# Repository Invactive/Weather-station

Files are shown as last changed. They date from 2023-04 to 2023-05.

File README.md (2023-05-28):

# Weather-station
The PCB project of an external, autonomous weather station including a battery-powered system for monitoring atmospheric conditions using 5 weather sensors. 
The STM32 microcontroller was used to operate the sensors, while a LoRaWAN radio communication module was utilized for long-range, wireless data transmission.

## General information:

The PCB project was implemented on a FR-4 laminate with a thickness of 1.5mm and dimensions of 90x32mm, consisting of two signal layers. 

The copper tracks have a thickness of 35μm. 

The board includes a 2-pin JST-XH power connector, a programmer/debugger 8-pin connector for the microcontroller, and an SMA antenna connector. 

To obtain +5V and +3.3V voltages, two voltage converters were used (with a maximum supply voltage of +5.5V). 

The maximum current consumption calculated for the entire circuit is approximately 500mA. 

The device can be battery powered (max. input voltage 5.5V).

Data from the sensors are transmitted via I2C, SPI and Analog.

Project includes: schematics, PCB, BOM, datasheets, 3D view, Gerber and drill files.

## Modules:
- STM32 MCU
- 5 weather conditions sensors
- LoRaWAN module for wireless communication
- Battery voltage measurement unit 
- Power supply unit (includes boost converters TPS61023DRLR)

## Main Components:
- MCU - STM32F301C8T6TR
- LoraWAN - RFM95W-868S2R
- Metal Oxide Gas Sensor - MICS-6814
- Air Pressure Sensor - KP254
- Humidity Sensor - HIH6020-021-001
- Temperature Sensor - TMP36GT9Z
- Ambient Light Sensor - BH1750FVI-TR
- Boost Converter - TPS61023DRLR

## Schematics:
[](Electrical_Schematics/weather_station_schematics.pdf)

## PCB:
[](src/PCB.pdf)
[](src/PCB_front.pdf)
[](src/PCB_back.pdf)

## 3D Views:
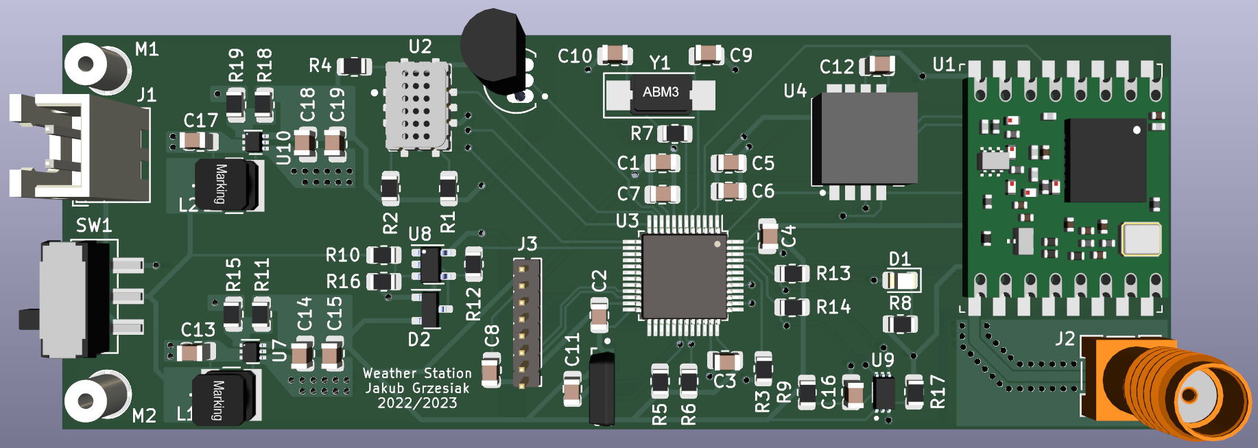
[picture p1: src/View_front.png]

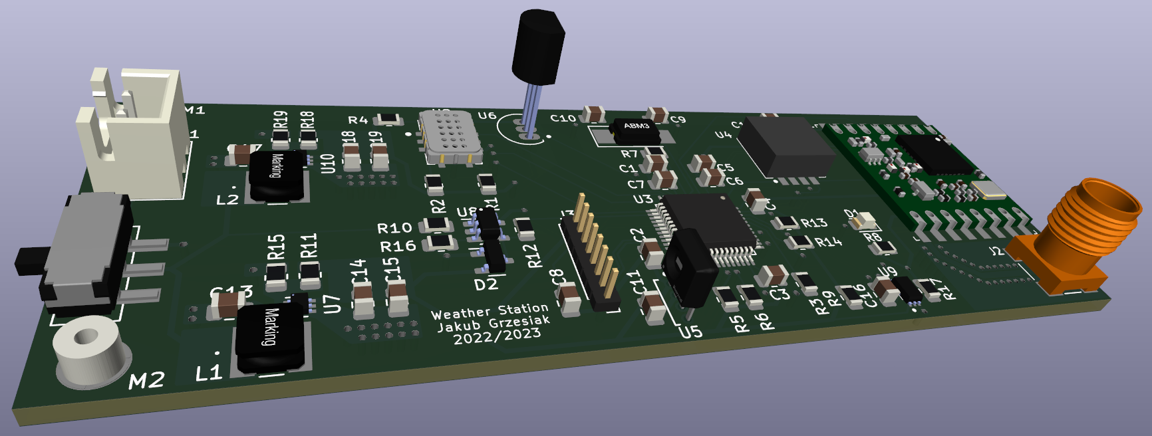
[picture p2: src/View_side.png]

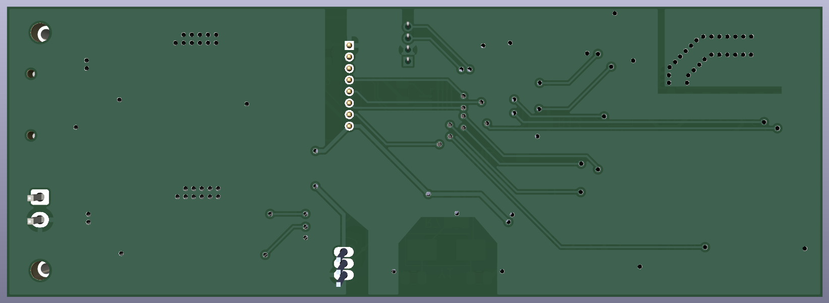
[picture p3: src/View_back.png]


---
Project designed in KiCAD 6.0.

Author: Jakub Grzesiak

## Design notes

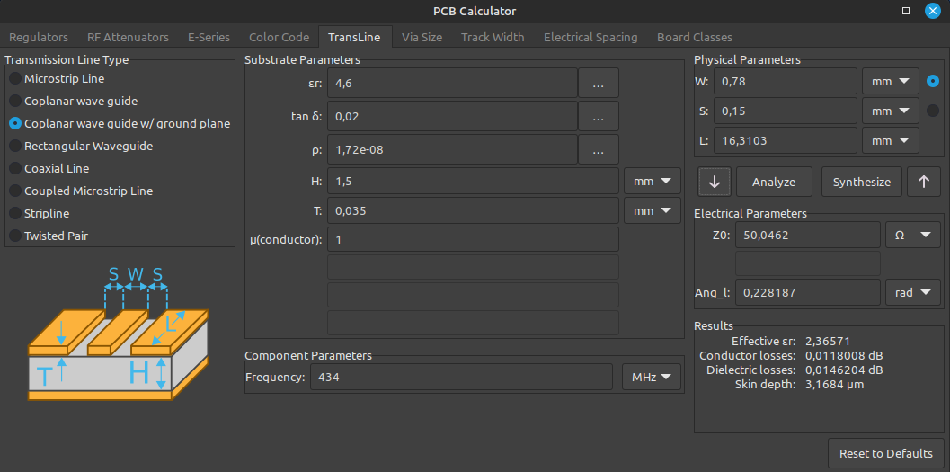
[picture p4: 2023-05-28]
src/imp_calc.png

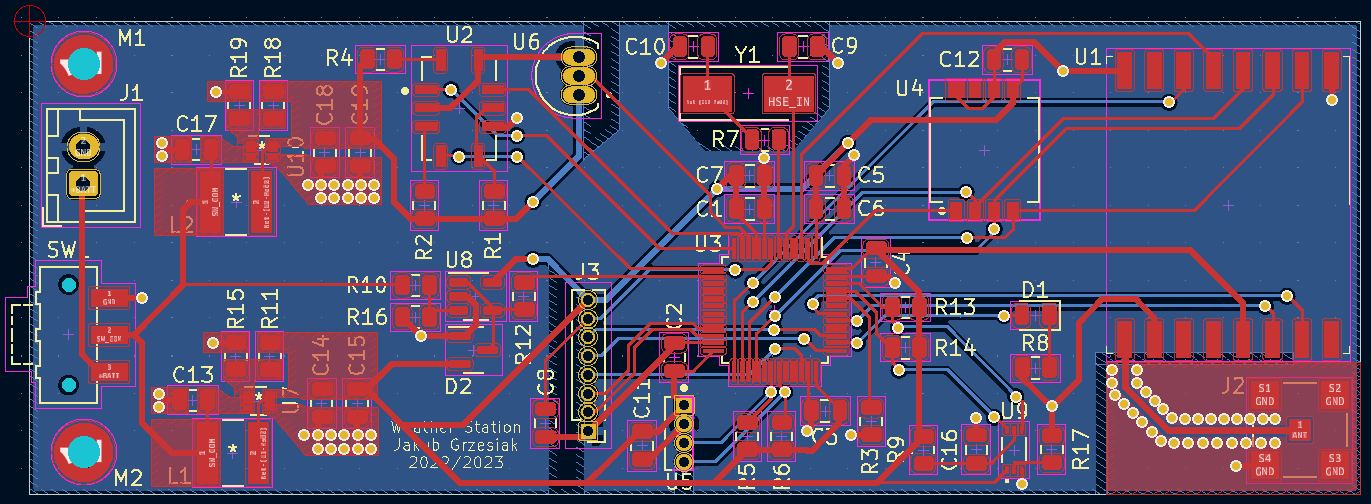
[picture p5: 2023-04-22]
src/PCB.png

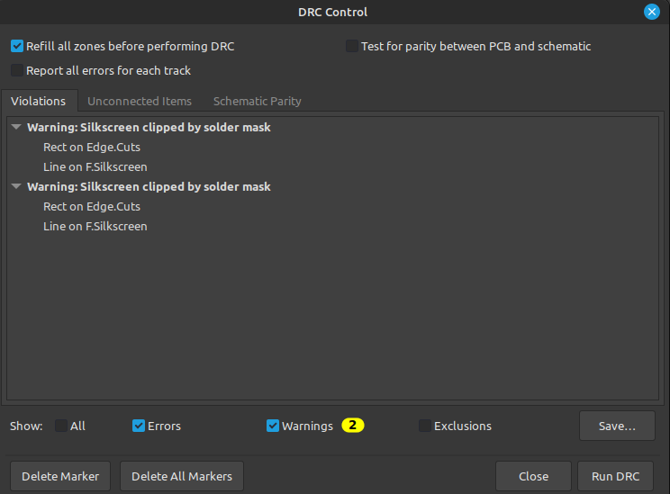
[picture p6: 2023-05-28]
src/DRC.png

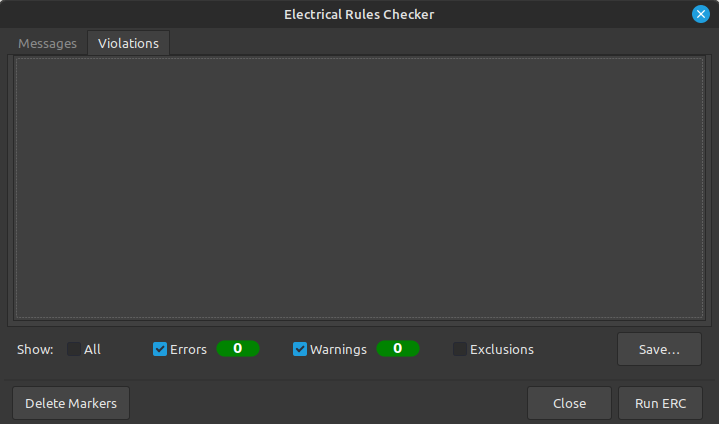
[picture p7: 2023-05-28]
src/ERC.png

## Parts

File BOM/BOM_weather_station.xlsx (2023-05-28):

Project: | Weather Station
Author: | Jakub Grzesiak
Source: | /home/jakub/Weather station/KiCAD_Project_Files/weather_station.kicad_sch
Date: | 2023-01-02 00:04
Tool: | Eeschema (6.0.7)
Generator: | /usr/share/kicad/plugins/bom_csv_grouped_by_value_with_fp.py
Number of components per 1 PCB: | 58
No. | Ref | Quantity | Value | Name | Footprint | Description | Vendor | Unit cost (1 item) | Price (1 PCB) | Unit cost (10 items) | Price (10 PCB) | Unit cost (100 items) | Price (100 PCB) | Link
1 | C1, C2, C3, C4, C8, C12 | 6 | 100nF | C | Capacitor_SMD:C_0805_2012Metric | Unpolarized capacitor | Mouser.pl | 0.48 zł | 2.89 zł | 0.11 zł | 6.66 zł | 0.05 zł | 31.80 zł | https://www.mouser.pl/ProductDetail/Samsung-Electro-Mechanics/CL21B104KACNFNC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
2 | C5 | 1 | 4.7uF | C | Capacitor_SMD:C_0805_2012Metric | Unpolarized capacitor | Mouser.pl | 0.48 zł | 0.48 zł | 0.18 zł | 1.83 zł | 0.15 zł | 14.90 zł | https://www.mouser.pl/ProductDetail/Samsung-Electro-Mechanics/CL21A475KPFNNNG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
3 | C6 | 1 | 1uF | C | Capacitor_SMD:C_0805_2012Metric | Unpolarized capacitor | Mouser.pl | 0.48 zł | 0.48 zł | 0.18 zł | 1.83 zł | 0.15 zł | 14.90 zł | https://www.mouser.pl/ProductDetail/Samsung-Electro-Mechanics/CL21B105KOFNNWE?qs=yOVawPpwOwmk953lizFBNA%3D%3D
4 | C7 | 1 | 10nF | C | Capacitor_SMD:C_0805_2012Metric | Unpolarized capacitor | Mouser.pl | 0.48 zł | 0.48 zł | 0.12 zł | 1.15 zł | 0.10 zł | 9.60 zł | https://www.mouser.pl/ProductDetail/Samsung-Electro-Mechanics/CL21B103KAANNNC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
5 | C9, C10 | 2 | 20pF | C | Capacitor_SMD:C_0805_2012Metric | Unpolarized capacitor | Mouser.pl | 0.56 zł | 1.11 zł | 0.26 zł | 5.20 zł | 0.20 zł | 40.40 zł | https://www.mouser.pl/ProductDetail/YAGEO/CC0805JRNPO9BN200
6 | C11 | 1 | 0.22uF | C | Capacitor_SMD:C_0805_2012Metric | Unpolarized capacitor | Mouser.pl | 0.72 zł | 0.72 zł | 0.34 zł | 3.37 zł | 0.25 zł | 24.50 zł | https://www.mouser.pl/ProductDetail/KYOCERA-AVX/08053C224K4T2A
7 | C13 | 1 | 2.2uF 4.06mR | C | Capacitor_SMD:C_0805_2012Metric | Unpolarized capacitor | Mouser.pl | 0.91 zł | 0.91 zł | 0.39 zł | 3.90 zł | 0.31 zł | 30.80 zł | https://www.mouser.pl/ProductDetail/TDK/C2012X5R1A225K085AA?qs=iuKcRwBk4Q80WRz1xS%2FJlw%3D%3D
8 | C14, C15, C18, C19 | 4 | 2.2uF 7.77mR | C | Capacitor_SMD:C_0805_2012Metric | Unpolarized capacitor | TME.eu | 1.18 zł | 4.72 zł | 1.18 zł | 47.16 zł | 0.78 zł | 310.00 zł | https://www.tme.eu/pl/en/details/grm21br71e225ka73l/mlcc-smd-capacitors/murata/
9 | C16 | 1 | 0.1uF | C | Capacitor_SMD:C_0805_2012Metric | Unpolarized capacitor | Digikey.pl | 0.45 zł | 0.45 zł | 0.20 zł | 1.99 zł | 0.11 zł | 10.90 zł | https://www.digikey.pl/en/products/detail/CL21B104KBCNNNC/1276-1003-1-ND/3889089?curr=pln
10 | C17 | 1 | 10uF 3mR | C | Capacitor_SMD:C_0805_2012Metric | Unpolarized capacitor | Digikey.pl | 0.63 zł | 0.63 zł | 0.47 zł | 4.67 zł | 0.22 zł | 21.90 zł | https://www.digikey.pl/en/products/detail/C0805C106K8PAC7800/399-C0805C106K8PAC7800CT-ND/1090920?curr=pln
11 | D1 | 1 | LED | LED | LED_SMD:LED_0805_2012Metric | Light emitting diode | Digikey.pl | 0.86 zł | 0.86 zł | 0.86 zł | 8.60 zł | 0.68 zł | 68.40 zł | https://www.digikey.pl/en/products/detail/150080GS75000/732-4983-1-ND/4489913?curr=pln
12 | D2 | 1 | BAT54S | BAT54S | Package_TO_SOT_SMD:SOT-23 | Schottky barrier diode | Mouser.pl | 0.87 zł | 0.87 zł | 0.82 zł | 8.23 zł | 0.45 zł | 45.20 zł | https://www.mouser.pl/ProductDetail/onsemi/BAT54SLT1G?qs=vLkC5FC1VN9oCh8qaBIZiQ%3D%3D
13 | J1 | 1 | JST-XH | B2B-XH-A(LF)(SN) | Connector_JST:JST_XH_B2B-XH-A_1x02_P2.50mm_Vertical | JST-XH header connector 2-pin | Farnell.com | 0.42 zł | 0.42 zł | 0.42 zł | 4.20 zł | 0.42 zł | 42.00 zł | https://pl.farnell.com/jst-japan-solderless-terminals/b2b-xh-a-lf-sn/header-vertical-2way/dp/1516276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
14 | J2 | 1 | SMA Antenna Connector | 73251-1350 | MOLEX_SMA_73251-1350:MOLEX_73251-1350 | SMA header antenna connector | Digikey.pl | 19.12 zł | 19.12 zł | 16.82 zł | 168.20 zł | 13.38 zł | 1338.00 zł | https://www.digikey.pl/en/products/detail/0732511350/WM9357-ND/3468834?curr=pln
15 | J3 | 1 | Debug Connector | Conn_01x08_Male | Connector_PinHeader_1.27mm:PinHeader_1x08_P1.27mm_Vertical | Generic connector, single row, 01x08, script generated (kicad-library-utils/schlib/autogen/connector/) | TME.eu | 0.93 zł | 0.93 zł | 0.93 zł | 9.26 zł | 0.58 zł | 58.10 zł | https://www.tme.eu/en/details/zl319-8p/pin-headers/connfly/ds1031-01-1-8p8bv3-1/
16 | L1, L2 | 2 | 1uH 17mR | L | 74404043010A:74404043010A | Inductor 74404043010A | Mouser.pl | 3.03 zł | 6.06 zł | 3.03 zł | 60.60 zł | 1.93 zł | 386.00 zł | https://www.mouser.pl/ProductDetail/Wurth-Elektronik/74404043010A?qs=h3%2Fj8evtlm0a71lUla1Ygg%3D%3D
17 | R1 | 1 | 820R | R | Resistor_SMD:R_0805_2012Metric | Resistor | Digikey.pl | 0.45 zł | 0.45 zł | 0.21 zł | 2.08 zł | 0.09 zł | 8.50 zł | https://www.digikey.pl/en/products/detail/CRGCQ0805F820R/A129748CT-ND/8577580?curr=pln
18 | R2 | 1 | 27R | R | Resistor_SMD:R_0805_2012Metric | Resistor | Digikey.pl | 0.45 zł | 0.45 zł | 0.21 zł | 2.08 zł | 0.09 zł | 8.50 zł | https://www.digikey.pl/en/products/detail/CRG0805F27R/A126357CT-ND/7603412?curr=pln
19 | R3, R17 | 2 | 10k | R | Resistor_SMD:R_0805_2012Metric | Resistor | Digikey.pl | 0.45 zł | 0.90 zł | 0.16 zł | 3.18 zł | 0.07 zł | 13.00 zł | https://www.digikey.pl/en/products/detail/CRGCQ0805J10K/A130140CT-ND/8577972?curr=pln
20 | R4 | 1 | 130R | R | Resistor_SMD:R_0805_2012Metric | Resistor | Digikey.pl | 0.45 zł | 0.45 zł | 0.30 zł | 3.04 zł | 0.12 zł | 12.30 zł | https://www.digikey.pl/en/products/detail/CRCW0805130RFKEA/541-130CCT-ND/1180681?curr=pln
21 | R5, R6 | 2 | 2k2 | R | Resistor_SMD:R_0805_2012Metric | Resistor | Digikey.pl | 0.45 zł | 0.90 zł | 0.17 zł | 3.36 zł | 0.07 zł | 13.60 zł | https://www.digikey.pl/en/products/detail/CRGCQ0805J2K2/A130136CT-ND/8577968?curr=pln
22 | R7 | 1 | 390R | R | Resistor_SMD:R_0805_2012Metric | Resistor | Digikey.pl | 0.45 zł | 0.45 zł | 0.40 zł | 3.99 zł | 0.15 zł | 15.40 zł | https://www.digikey.pl/en/products/detail/ERJ-6ENF3900V/P390CCT-ND/1746861?curr=pln
23 | R8 | 1 | 100R | R | Resistor_SMD:R_0805_2012Metric | Resistor | Digikey.pl | 0.50 zł | 0.50 zł | 0.44 zł | 4.39 zł | 0.17 zł | 16.90 zł | https://www.digikey.pl/en/products/detail/CRGH0805F100R/A126416CT-ND/7603471?curr=pln
24 | R9 | 1 | 1k | R | Resistor_SMD:R_0805_2012Metric | Resistor | Digikey.pl | 0.45 zł | 0.45 zł | 0.16 zł | 1.63 zł | 0.07 zł | 6.70 zł | https://www.digikey.pl/en/products/detail/RC0805FR-101KL/13-RC0805FR-101KLCT-ND/13694478?curr=pln
25 | R10, R15, R16, R19 | 4 | 100k | R | Resistor_SMD:R_0805_2012Metric | Resistor | Mouser.pl | 0.48 zł | 1.92 zł | 0.25 zł | 10.00 zł | 0.11 zł | 44.40 zł | https://www.mouser.pl/ProductDetail/Bourns/CR0805AFX-1003ELF
26 | R11 | 1 | 453k | R | Resistor_SMD:R_0805_2012Metric | Resistor | Mouser.pl | 0.53 zł | 0.53 zł | 0.40 zł | 4.04 zł | 0.16 zł | 15.90 zł | https://www.mouser.pl/ProductDetail/Panasonic/ERJ-6ENF4533V?qs=sGAEpiMZZMtlubZbdhIBINbsJb0hdM3zu28clQM34zY%3D
27 | R12 | 1 | 200R | R | Resistor_SMD:R_0805_2012Metric | Resistor | Digikey.pl | 0.45 zł | 0.45 zł | 0.11 zł | 1.13 zł | 0.05 zł | 4.70 zł | https://www.digikey.pl/en/products/detail/CR0805-FX-2000ELF/118-CR0805-FX-2000ELFCT-ND/3925388?curr=pln
28 | R13, R14 | 2 | 4k7 | R | Resistor_SMD:R_0805_2012Metric | Resistor | Digikey.pl | 0.45 zł | 0.90 zł | 0.21 zł | 4.16 zł | 0.09 zł | 17.00 zł | https://www.digikey.pl/en/products/detail/CRGCQ0805F4K7/A129757CT-ND/8577589?curr=pln
29 | R18 | 1 | 732k | R | Resistor_SMD:R_0805_2012Metric | Resistor | Mouser.pl | 0.48 zł | 0.48 zł | 0.40 zł | 4.04 zł | 0.16 zł | 15.90 zł | https://www.mouser.pl/ProductDetail/Panasonic/ERJ-6ENF7323V
30 | SW1 | 1 | SW_MAIN_PWR | SW_SPDT | Button_Switch_SMD:SW_SPDT_CK-JS102011SAQN | Switch, single pole double throw | Digikey.pl | 2.99 zł | 2.99 zł | 2.90 zł | 29.04 zł | 2.79 zł | 279.40 zł | https://www.digikey.pl/en/products/detail/c-k/JS102011SAQN/1640095
31 | U1 | 1 | RFM95W-868S2 | RFM95W-868S2 | RF_Module:HOPERF_RFM69HW | LoraWAN module | TME.eu | 36.36 zł | 36.36 zł | 30.71 zł | 397.10 zł | 25.11 zł | 2511.00 zł | https://www.tme.eu/pl/en/details/rfm95w-868s2/rf-modules/hope-microelectronics/rfm95w-868s2r/
32 | U2 | 1 | MICS-6814 | MICS-6814 | MICS-6814:SENSOR_MICS-6814 | Air Quality Sensors MOS Triple Sensor | Mouser.pl | 58.49 zł | 58.49 zł | 53.73 zł | 573.30 zł | 53.20 zł | 5320.00 zł | https://www.mouser.pl/ProductDetail/Amphenol-SGX-Sensortech/MICS-6814?qs=YCa%2FAAYMW01pNK%252BnW3Jo7g%3D%3D
33 | U3 | 1 | STM32F301C8T6TR | STM32F301C8Tx | Package_QFP:LQFP-48_7x7mm_P0.5mm | ARM Cortex-M4 MCU, 64KB flash, 16KB RAM, 72MHz, 2-3.6V, 37 GPIO, LQFP-48 | Farnell.com | 18.83 zł | 18.83 zł | 16.92 zł | 169.20 zł | 13.84 zł | 1384.00 zł | https://pl.farnell.com/stmicroelectronics/stm32f301c8t6tr/mcu-32bit-cortex-m4-72mhz-lqfp/dp/2503249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
34 | U4 | 1 | KP254 | KP254 | KP254:Infineon-KP254-Manufacturer_Recommended | KP254 | Farnell.com | 39.61 zł | 39.61 zł | 31.55 zł | 315.50 zł | 25.16 zł | 2516.00 zł | https://pl.farnell.com/infineon/kp254xtma2/pressure-sensor-absolute-40kpa/dp/3816971?CMP=GRHB-OCTOPART
35 | U5 | 1 | HIH6020-021-001 | HIH6020-021-001 | HIH7120-021-001:Honeywell-HIH7120-021-001-Recommended_Land_Pattern_ | HIH7120-021-001 | Mouser.pl | 63.35 zł | 63.35 zł | 57.62 zł | 576.20 zł | 48.97 zł | 4897.00 zł | https://www.mouser.pl/ProductDetail/Honeywell/HIH6020-021-001?qs=jvB%252BdWhGd43%2FZG9ey9bbTQ%3D%3D
36 | U6 | 1 | TMP36GT9Z | TMP36GT9Z | TMP36GT9Z:TO92127P521H733-3 | Board Mount Temperature Sensor | Mouser.pl | 9.76 zł | 9.76 zł | 8.75 zł | 87.50 zł | 7.02 zł | 702.00 zł | https://www.mouser.pl/ProductDetail/Analog-Devices/TMP36GT9Z?qs=WIvQP4zGanhT97N47MSoHw%3D%3D
37 | U7, U10 | 2 | TPS61023DRLR | TPS61023DRLR | TPS61023DRLR:TPS61023DRLR | Boost converter | Mouser.pl | 5.92 zł | 11.84 zł | 5.34 zł | 106.80 zł | 4.14 zł | 828.00 zł | https://www.mouser.pl/ProductDetail/Texas-Instruments/TPS61023DRLT?qs=BJlw7L4Cy78Zr3IJIU3gNw%3D%3D&vip=1
38 | U8 | 1 | INA180A1 | INA180A1 | Package_TO_SOT_SMD:SOT-23-5 | Current Sense Amplifier, 1 Circuit, Rail-to-Rail, 26V, Gain 20 V/V, SOT-23-5 | Mouser.pl | 2.45 zł | 2.45 zł | 2.09 zł | 20.90 zł | 1.56 zł | 156.00 zł | https://www.mouser.pl/ProductDetail/Texas-Instruments/INA180A1IDBVR?qs=5aG0NVq1C4wnkaOukGk95A%3D%3D
39 | U9 | 1 | BH1750FVI-TR | BH1750FVI-TR | BH1750FVI-TR:XDCR_BH1750FVI-TR | Ambient light sensor | Farnell.com | 21.06 zł | 21.06 zł | 13.89 zł | 138.90 zł | 13.33 zł | 1333.00 zł | https://pl.farnell.com/rohm/bh1750fvi-tr/ambient-light-sensor-i2c-wsof/dp/2421284?CMP=GRHB-OCTOPART
40 | Y1 | 1 | ABM3-8.000MHZ-D2Y | ABM3-8.000MHZ-D2Y | Crystal:Crystal_SMD_Abracon_ABM3-2Pin_5.0x3.2mm_HandSoldering | Miniature ceramic SMD crystal | Farnell.com | 2.22 zł | 2.22 zł | 2.22 zł | 22.20 zł | 2.13 zł | 213.00 zł | https://pl.farnell.com/abracon/abm3-8-000mhz-d2y-t/crystal-8mhz-18pf-smd/dp/2101329?CMP=GRHB-OCTOPART
41 |  | 1 | TI.85.2113 | TI.85.2113 |  | External antenna 868MHZ TERMINAL DIPOLE ANTENNA | Mouser.pl | 40.93 zł | 40.93 zł | 40.93 zł | 409.30 zł | 32.71 zł | 3271.00 zł | https://www.mouser.pl/ProductDetail/Taoglas/TI.85.2113?qs=P1JMDcb91o7IOmGnFabR3w%3D%3D
 |  |  |  |  |  |  | Cost Summary | 1 PCB |  | 10 PCB |  | 100 PCB
 |  |  |  |  |  |  |  | Total | Per 1 PCB | Total | Per 1 PCB | Total | Per 1 PCB
 |  |  |  |  |  |  | Total cost of components: | 357.85 zł | 357.85 zł | 3229.91 zł | 296.38 zł | 26050.60 zł | 251.12 zł
 |  |  |  |  |  |  | PCB manufacturing cost: | 8.74 zł | 8.74 zł | 21.86 zł | 2.19 zł | 94.42 zł | 0.94 zł
 |  |  |  |  |  |  | Total: | 366.59 zł | 366.59 zł | 3251.77 zł | 298.57 zł | 26145.02 zł | 252.06 zł

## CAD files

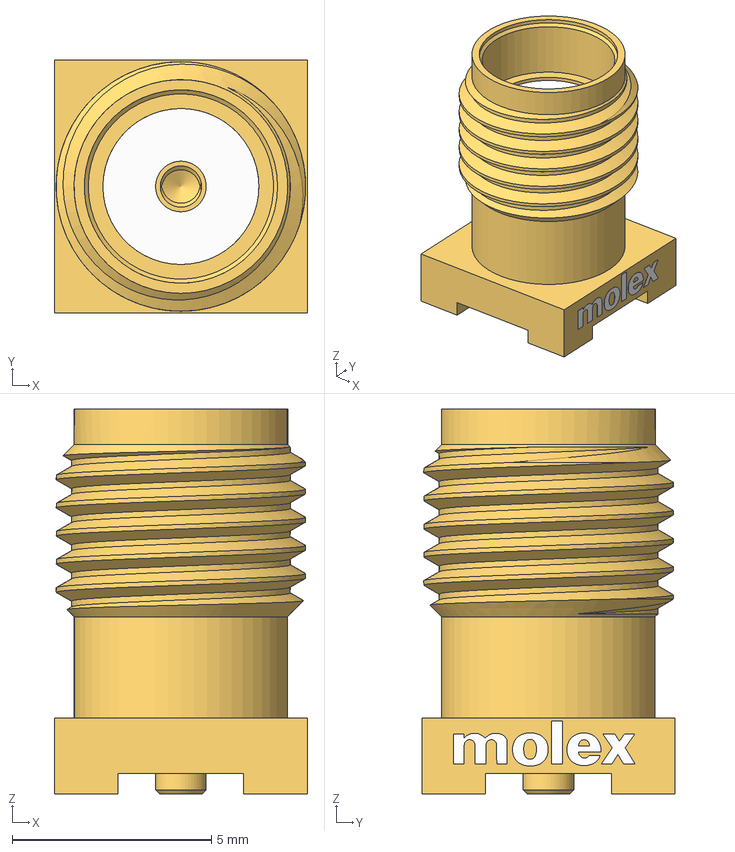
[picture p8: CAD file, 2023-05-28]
3D_Models/Molex_-_73251-1350.step
6.35 x 6.35 x 9.66 mm
isolator
Molex

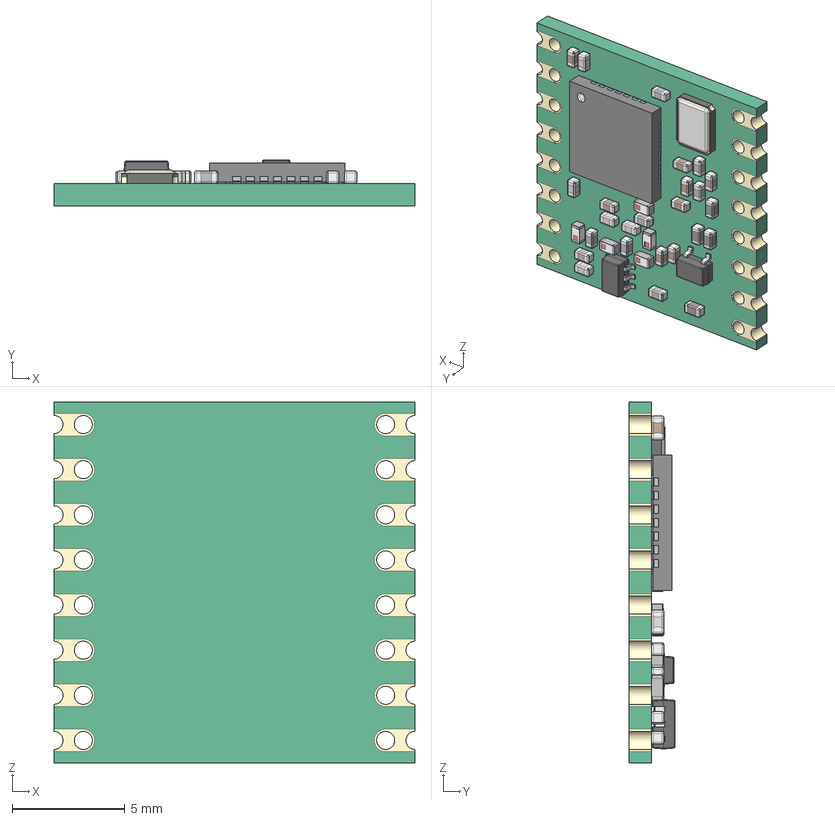
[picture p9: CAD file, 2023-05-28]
3D_Models/RFM95 LoRa v15.step
16.0 x 2.04 x 16.0 mm
QFN 28
SMD Crystal
CAP 0403 x 8
CAP Ceramic 0403 x 8
Res 0403 x 4
CAP ML 0403 x 5
SOT-323
Inductor SMD 0403 x 5
SOT-363

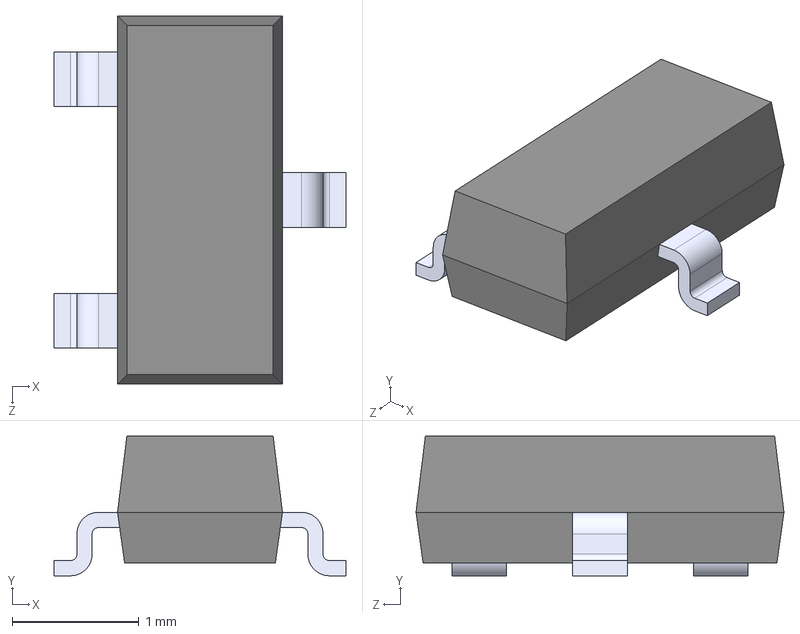
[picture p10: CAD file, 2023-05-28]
3D_Models/BAT54S,215.STEP
2.30 x 1.10 x 2.90 mm

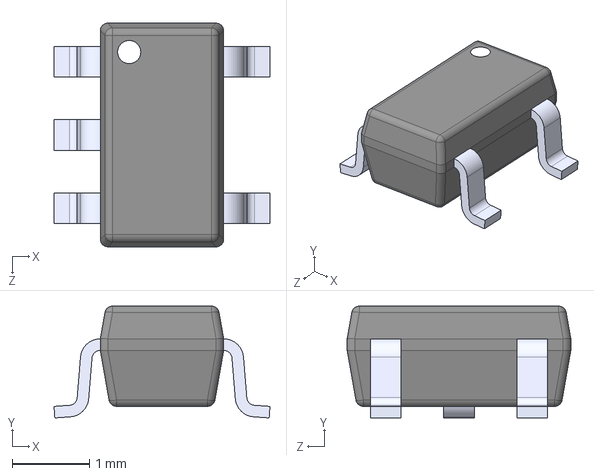
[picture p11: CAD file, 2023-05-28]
3D_Models/INA180B3IDBVR.STEP
2.80 x 1.45 x 2.90 mm

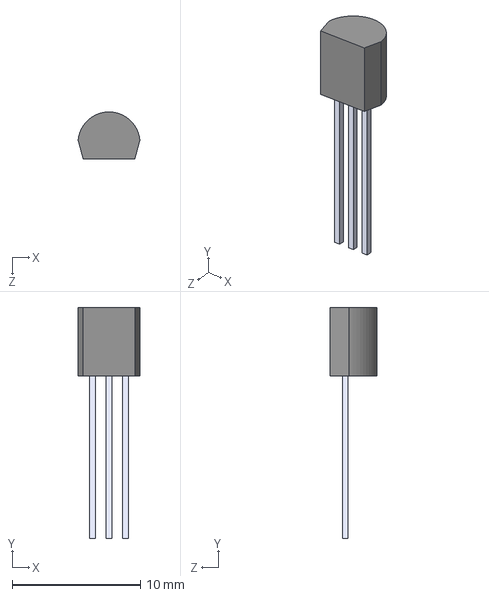
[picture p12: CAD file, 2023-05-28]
3D_Models/TMP36GT9Z--3DModel-STEP-269445.STEP
4.83 x 18.0 x 3.68 mm

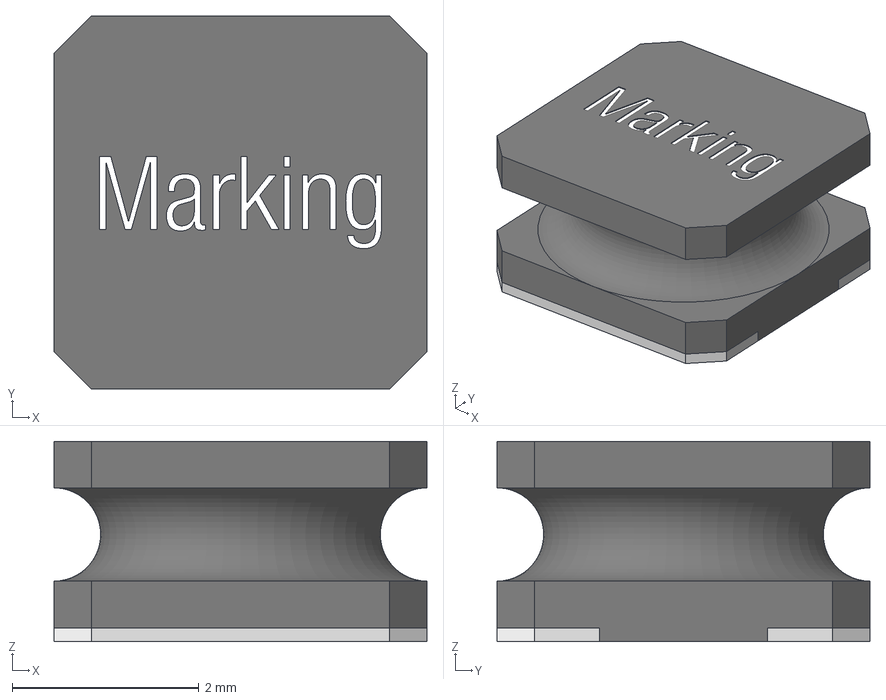
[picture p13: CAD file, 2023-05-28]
3D_Models/Download_STP_WE-LQS-4025 (rev1).stp
4.00 x 4.00 x 2.15 mm
Core
Contact x 2
Glue

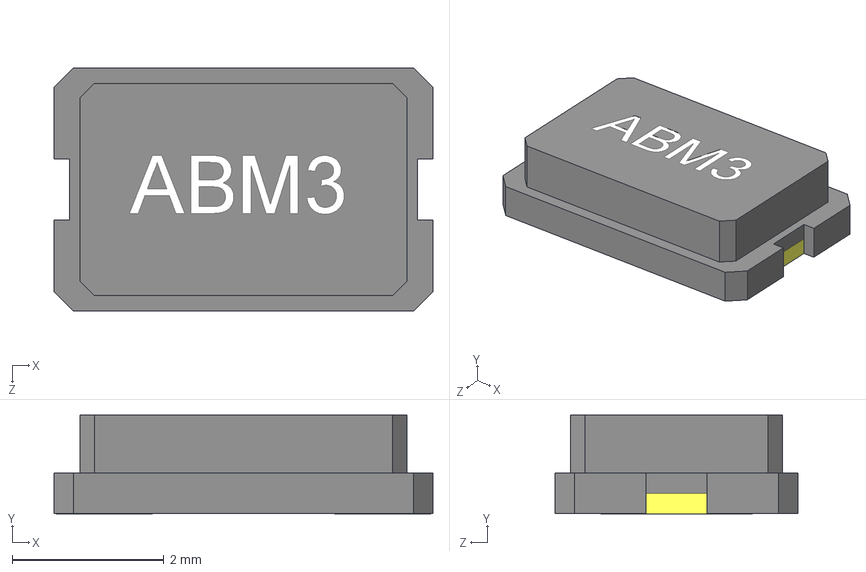
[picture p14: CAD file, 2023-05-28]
3D_Models/ABM3-8.000MHZ-D2Y-T--3DModel-STEP-400430.STEP
5.00 x 1.30 x 3.20 mm

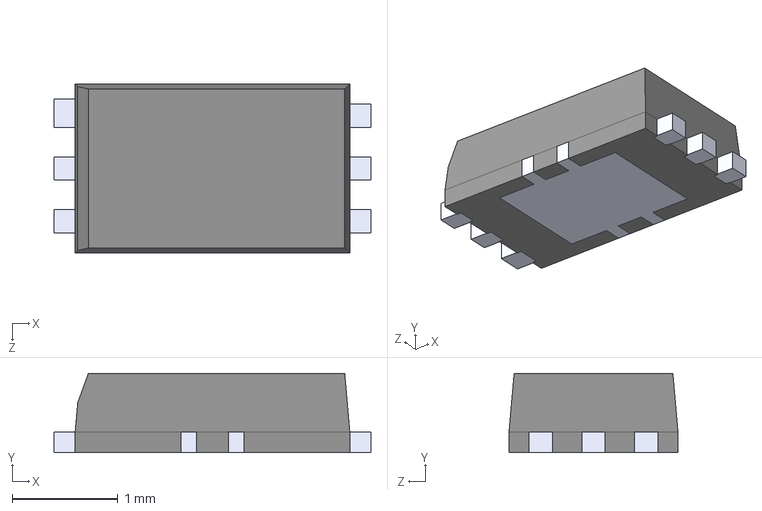
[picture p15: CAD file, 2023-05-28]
3D_Models/BH1750FVI-TR--3DModel-STEP-56544.STEP
3.00 x 0.75 x 1.60 mm

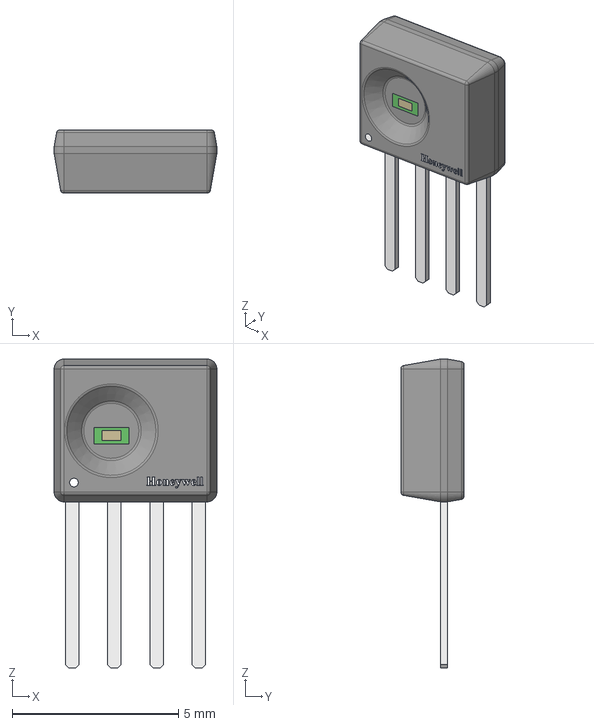
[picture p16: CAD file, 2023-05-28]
3D_Models/Honeywell_-_HIH7120-021-001.step
4.90 x 1.91 x 9.30 mm

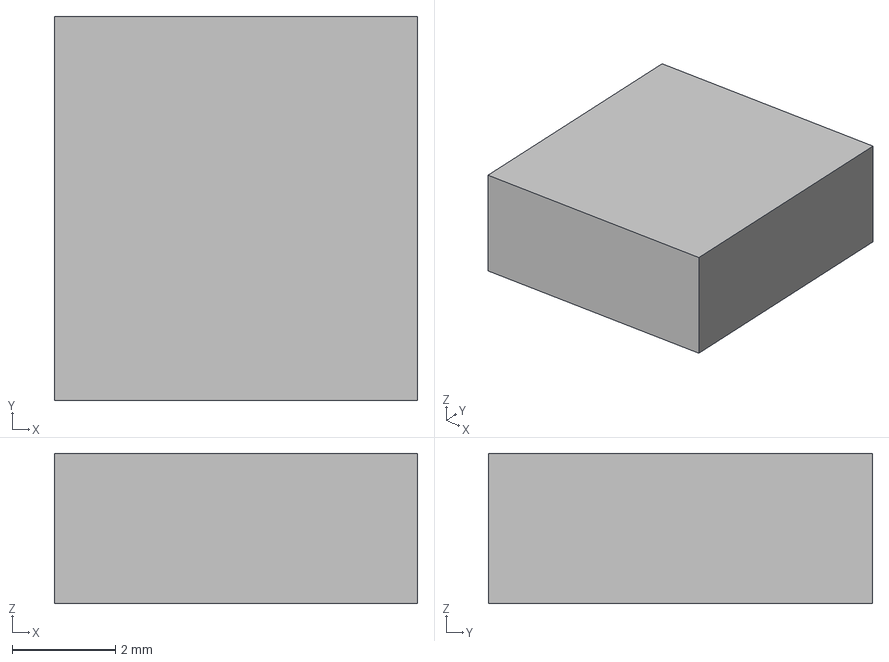
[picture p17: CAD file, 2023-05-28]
3D_Models/Infineon_-_KP254.step
7.02 x 7.42 x 2.90 mm

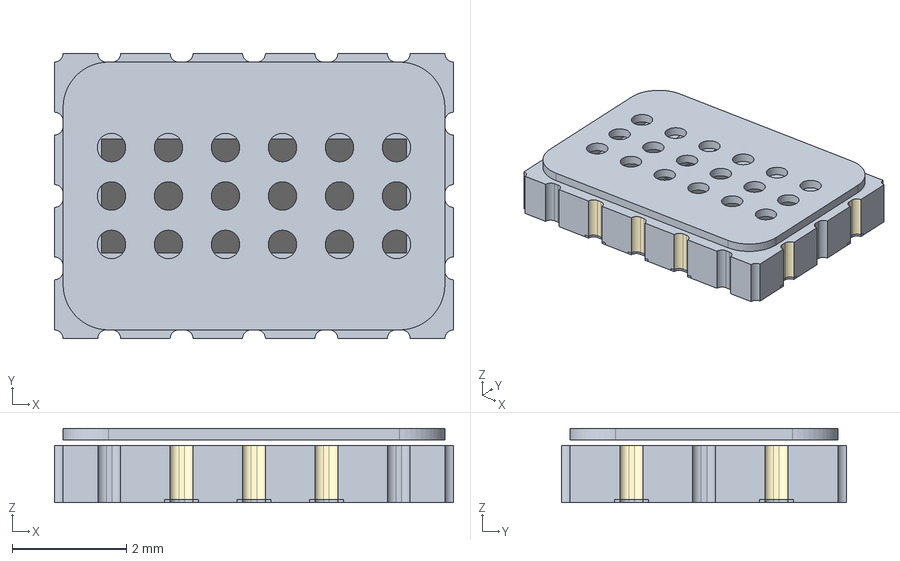
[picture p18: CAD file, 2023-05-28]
3D_Models/mics-6814_three_gas_sensor.stp
7.00 x 5.00 x 1.30 mm
lid

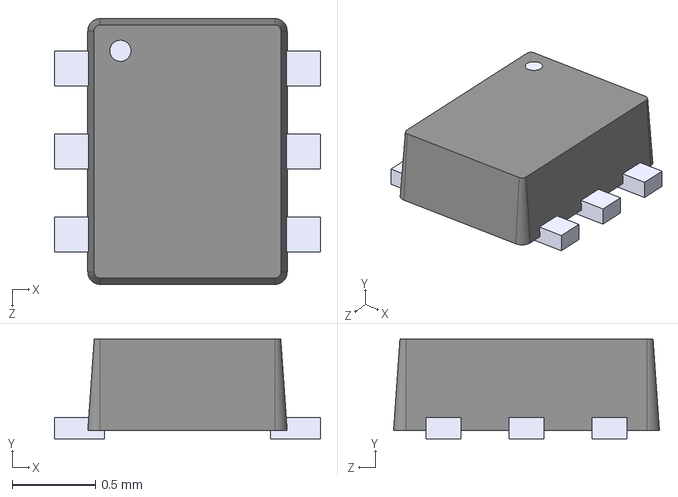
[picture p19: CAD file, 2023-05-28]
3D_Models/TPS61023DRLR.STEP
1.60 x 0.6 x 1.60 mm

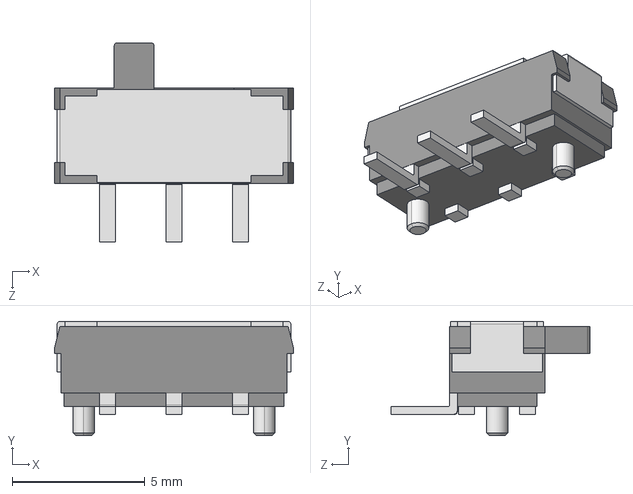
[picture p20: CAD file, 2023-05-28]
3D_Models/JS102011SAQN.STEP
9.00 x 4.30 x 7.50 mm

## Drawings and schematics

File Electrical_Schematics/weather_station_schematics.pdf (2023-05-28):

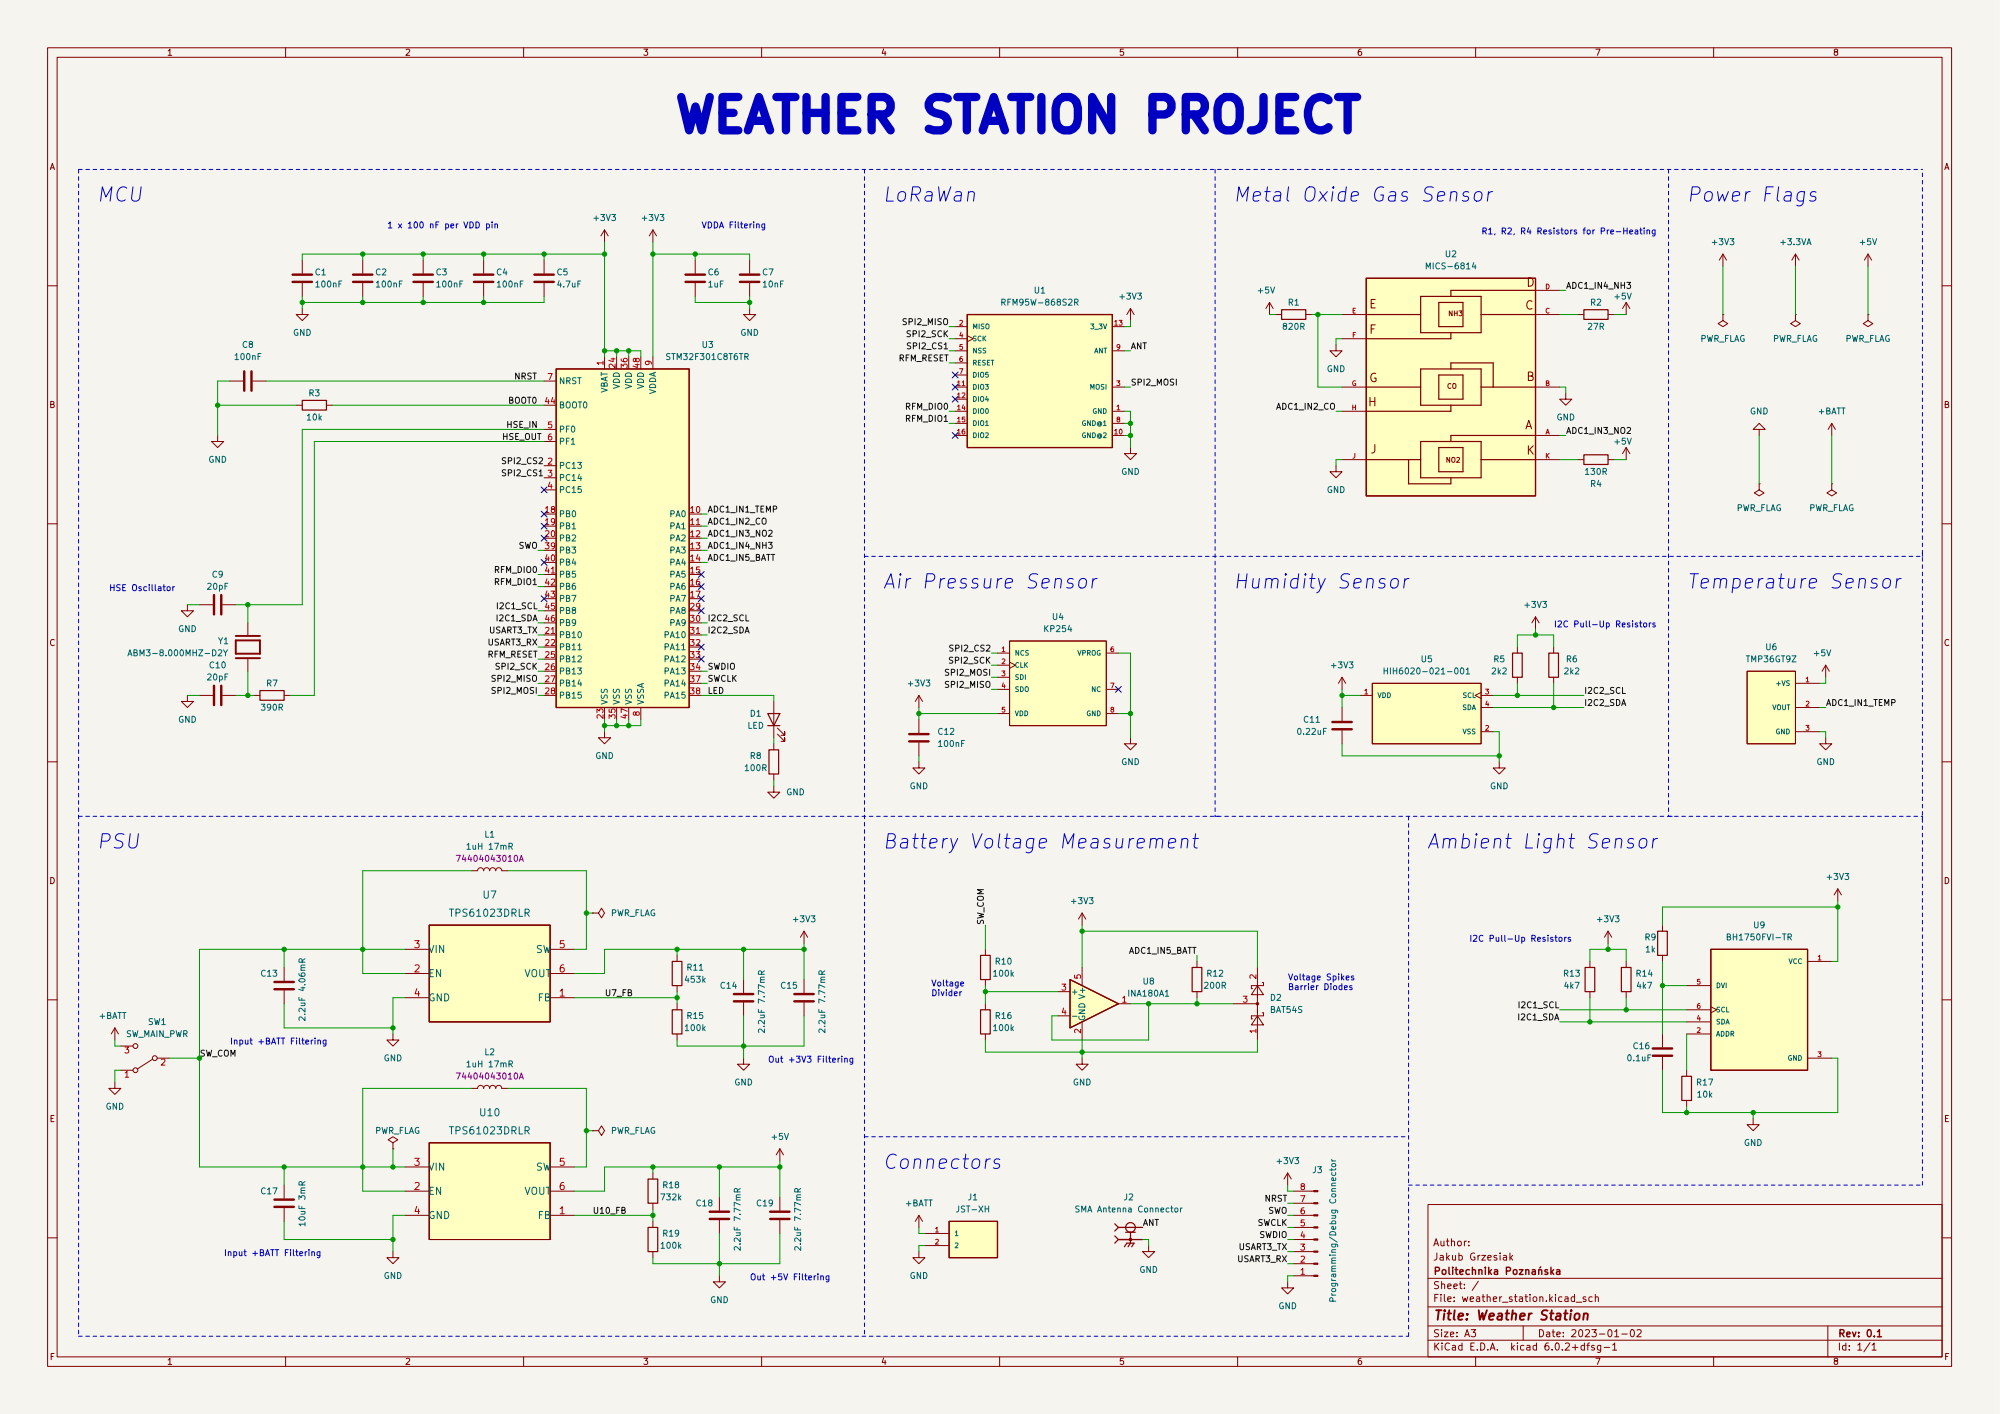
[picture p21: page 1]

Metal Oxide Gas Sensor

R1, R2, R4 Resistors for Pre-Heating

1 PA0 10 PA1 11 PA2 12 PA3 13 PA4 14 PA5 15 PA6 16 PA7 17 PB0 18 PB1 19 PC13 2 PB2 20 PB10 21 PB11 22 VSS 23 VDD 24 PB12 25 PB13 26 PB14 27 PB15 28 PA8 29 PC14 3 PA9 30 PA10 31 PA11 32 PA12 33 PA13 34 VSS 35 VDD 36 PA14 37 PA15 38 PB3 39 PC15 4 PB4 40 PB5 41 PB6 42 PB7 43 BOOT0 44 PB8 45 PB9 46 VSS 47 VDD 48 PF0 5 PF1 6 NRST 7 VSSA

J2 SMA Antenna Connector GND

Voltage Divider Battery Voltage Measurement

Voltage Spikes Barrier Diodes

J3 Programming/Debug Connector GND

Id: 1/1 Title: Weather Station

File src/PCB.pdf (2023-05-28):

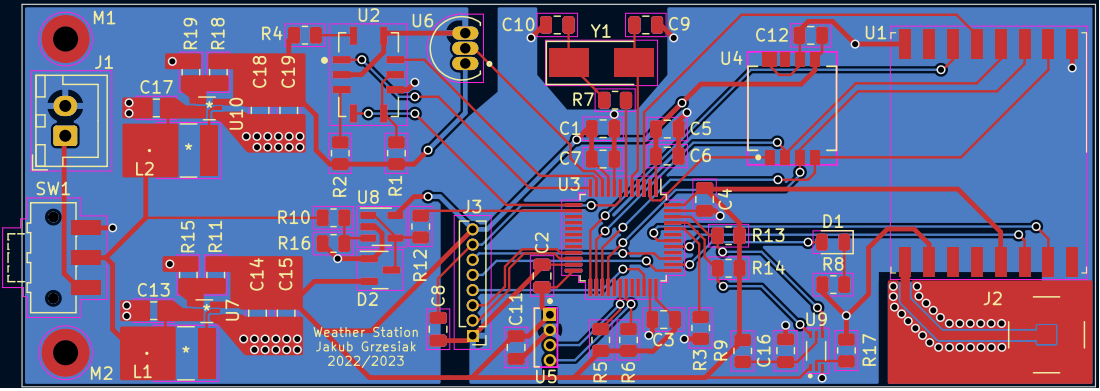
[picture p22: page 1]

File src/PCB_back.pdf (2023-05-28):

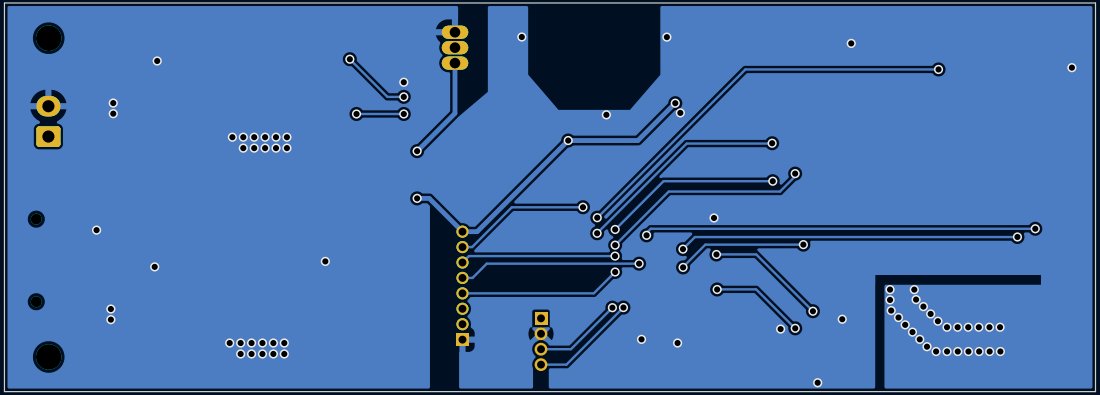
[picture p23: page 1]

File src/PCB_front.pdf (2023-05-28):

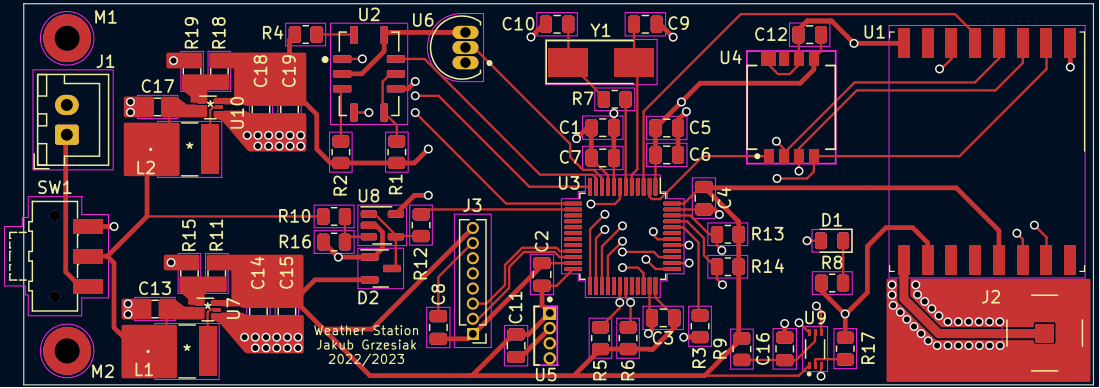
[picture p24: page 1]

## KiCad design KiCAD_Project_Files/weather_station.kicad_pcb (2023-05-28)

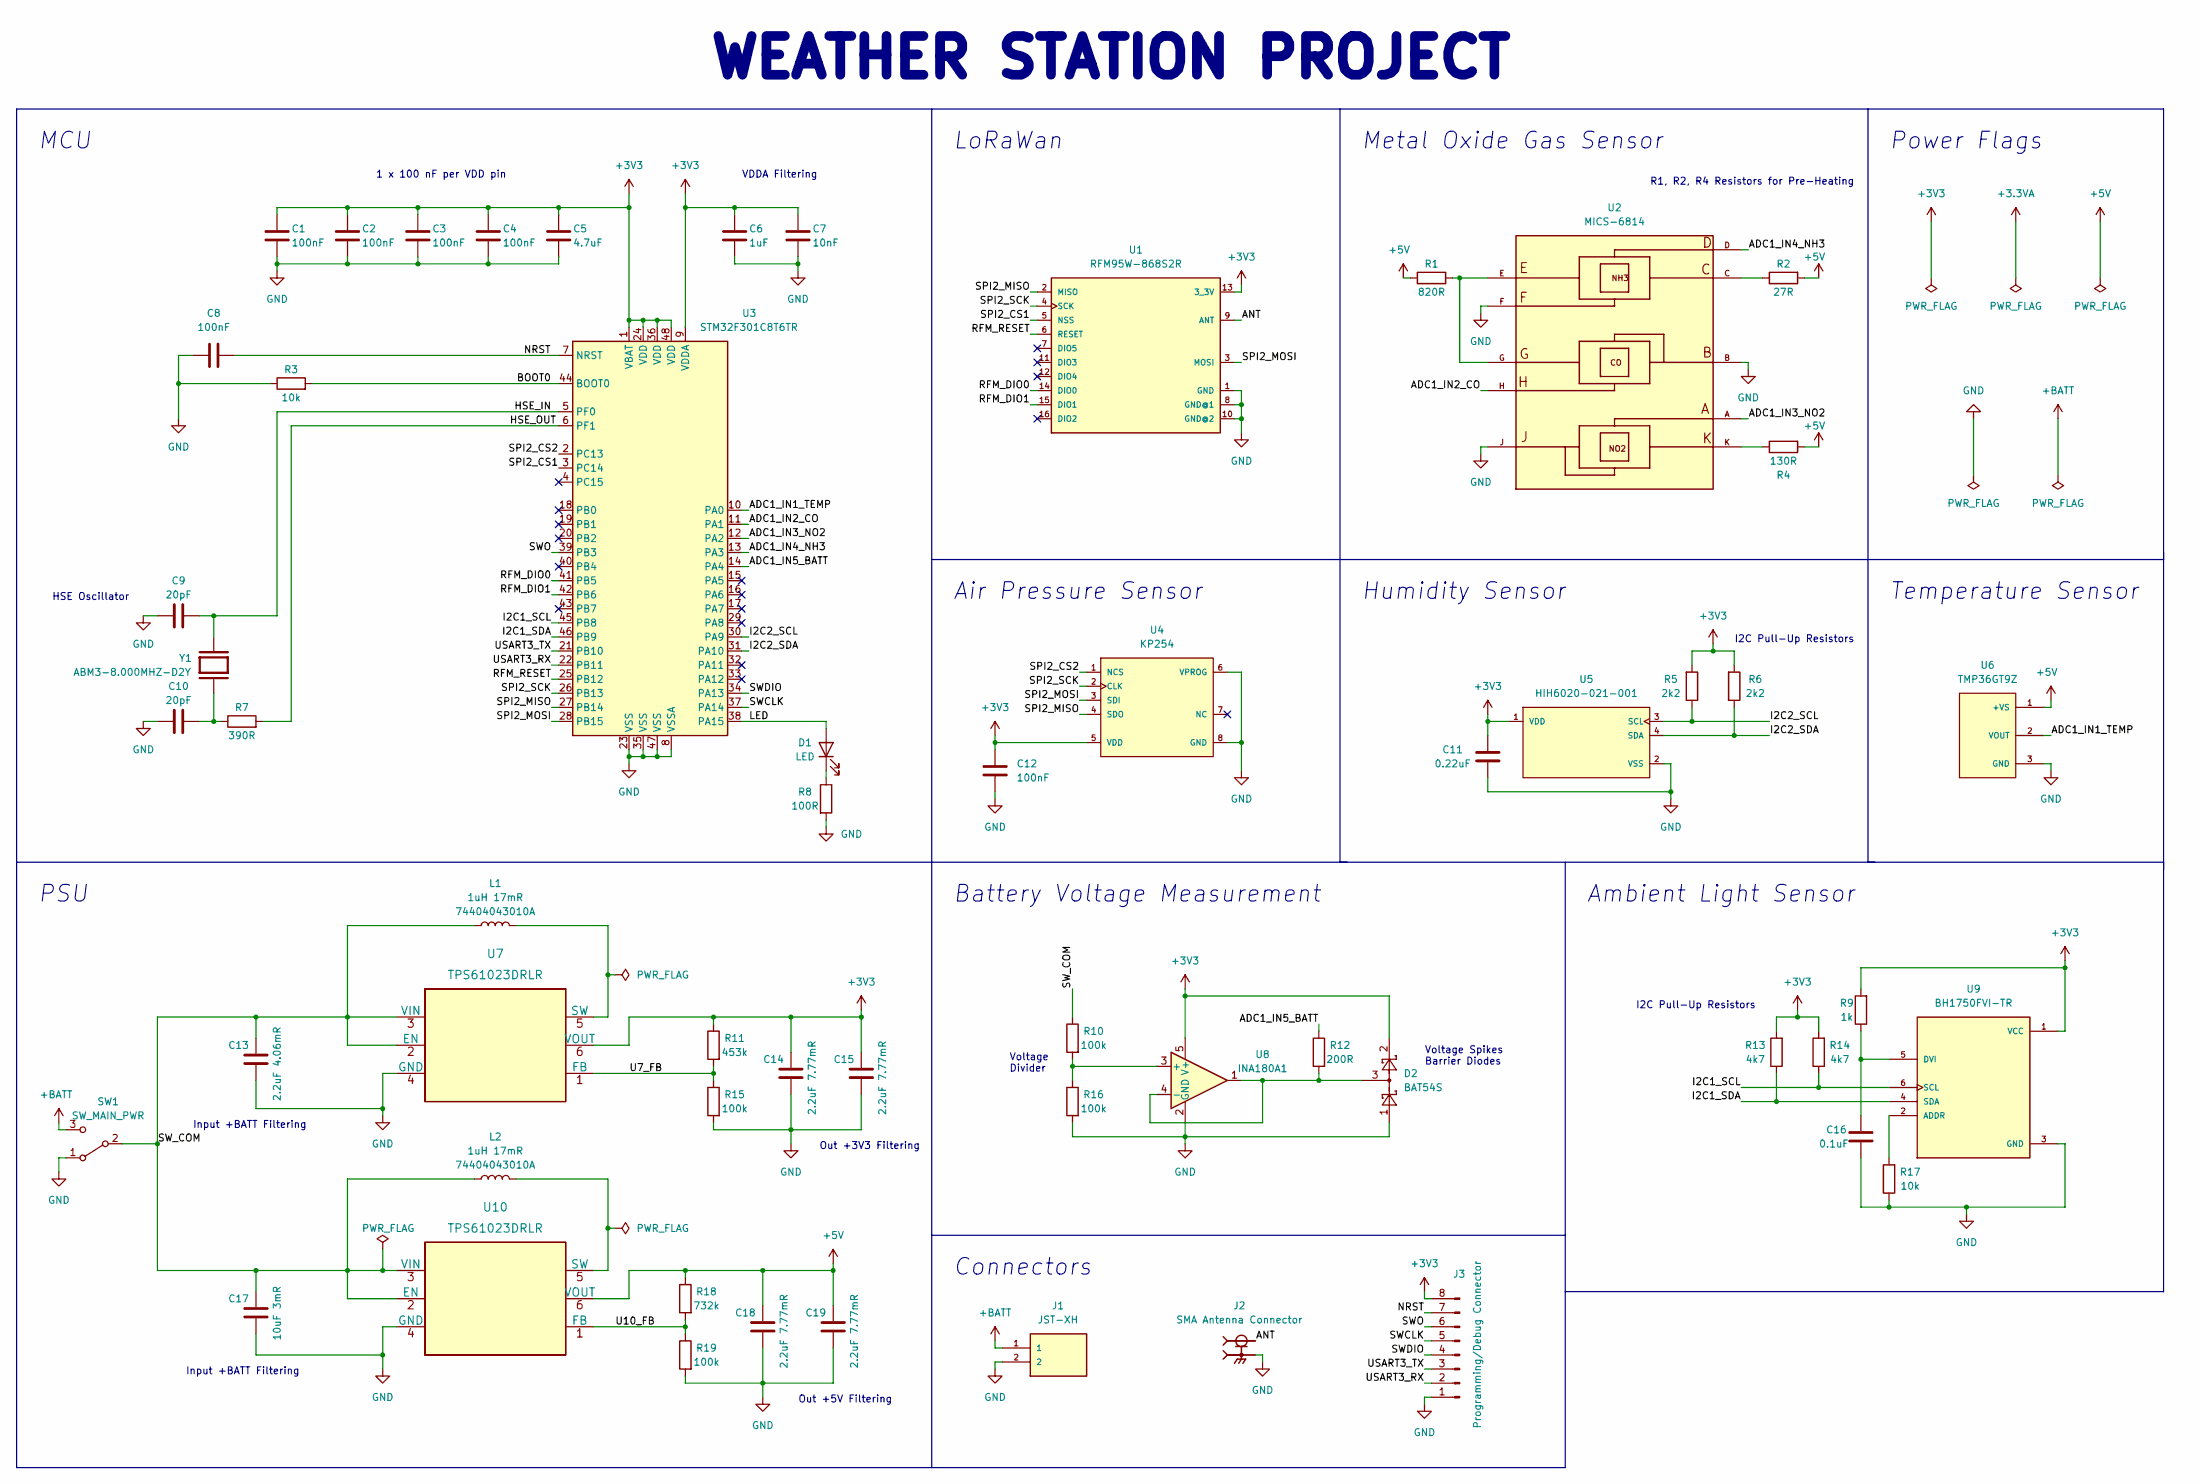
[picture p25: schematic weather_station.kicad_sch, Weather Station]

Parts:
C1, C2, C3, C4, C8, C12: 100nF; C_0805_2012Metric
C5: 4.7uF; C_0805_2012Metric
C6: 1uF; C_0805_2012Metric
C7: 10nF; C_0805_2012Metric
C9, C10: 20pF; C_0805_2012Metric
C11: 0.22uF; C_0805_2012Metric
C13: 2.2uF 4.06mR; C_0805_2012Metric
C14, C15: 2.2uF 7.77mR; C_0805_2012Metric; Part Num GRM21BR71E225KA73L
C16: 0.1uF; C_0805_2012Metric
C17: 10uF 3mR; C_0805_2012Metric
C18, C19: 2.2uF 7.77mR; C_0805_2012Metric
D1: LED; LED_0805_2012Metric
D2: BAT54S; SOT-23
J1: JST-XH; JST_XH_B2B-XH-A_1x02_P2.50mm_Vertical
J2: SMA Antenna Connector; MOLEX_73251-1350; PARTREV C4
J3: Programming/Debug Connector; PinHeader_1x08_P1.27mm_Vertical
L1, L2: 1uH 17mR; 74404043010A; Part Num 74404043010A
R1: 820R; R_0805_2012Metric
R2: 27R; R_0805_2012Metric
R3, R17: 10k; R_0805_2012Metric
R4: 130R; R_0805_2012Metric
R5, R6: 2k2; R_0805_2012Metric
R7: 390R; R_0805_2012Metric
R8: 100R; R_0805_2012Metric
R9: 1k; R_0805_2012Metric
R10, R15, R16, R19: 100k; R_0805_2012Metric
R11: 453k; R_0805_2012Metric
R12: 200R; R_0805_2012Metric
R13, R14: 4k7; R_0805_2012Metric
R18: 732k; R_0805_2012Metric
SW1: SW_MAIN_PWR; SW_SPDT_CK-JS102011SAQN
U1: RFM95W-868S2R; HOPERF_RFM69HW
U2: MICS-6814; SENSOR_MICS-6814
U3: STM32F301C8T6TR; LQFP-48_7x7mm_P0.5mm
U4: KP254; Infineon-KP254-Manufacturer_Recommended; Supply Voltage Range 3.3 to 5 V
U5: HIH6020-021-001; Honeywell-HIH7120-021-001-Recommended_Land_Pattern_; mouser part number 785-HIH7120-021-001; digikey description SENS HUMID/TEMP 3.3V I2C 3% 4SIP
U6: TMP36GT9Z; TO92127P521H733-3; PARTREV H
U7, U10: TPS61023DRLR
U8: INA180A1; SOT-23-5
U9: BH1750FVI-TR; XDCR_BH1750FVI-TR; PARTREV D
Y1: ABM3-8.000MHZ-D2Y; Crystal_SMD_Abracon_ABM3-2Pin_5.0x3.2mm_HandSoldering; PARTREV 4/25/2022

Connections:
+3V3: C1.2, C2.2, C3.2, C4.2, C5.2, C6.2, C7.2, C11.2, C12.1, C14.1, C15.1, D2.2, J3.8, R5.2, R6.2, R9.2, R11.1, R13.2, R14.2, U1.13 (3_3V), U3.1 (VBAT), U3.9 (VDDA), U3.24 (VDD), U3.36 (VDD), U3.48 (VDD), U4.5 (VDD), U5.1 (VDD), U7.6 (VOUT), U8.5 (V+), U9.1 (VCC)
+5V: C18.1, C19.1, R1.2, R2.2, R4.2, R18.1, U6.1 (+VS), U10.6 (VOUT)
+BATT: J1.1, SW1.3 (C)
/ADC1_IN1_TEMP: U3.10 (PA0), U6.2 (VOUT)
/ADC1_IN2_CO: U2.H, U3.11 (PA1)
/ADC1_IN3_NO2: U2.A, U3.12 (PA2)
/ADC1_IN4_NH3: U2.D, U3.13 (PA3)
/ADC1_IN5_BATT: R12.1, U3.14 (PA4)
/ANT: J2.1, U1.9 (ANT)
/BOOT0: R3.2, U3.44 (BOOT0)
/HSE_IN: C9.2, U3.5 (PF0), Y1.2
/HSE_OUT: R7.2, U3.6 (PF1)
/I2C1_SCL: R14.1, U3.45 (PB8), U9.6 (SCL)
/I2C1_SDA: R13.1, U3.46 (PB9), U9.4 (SDA)
/I2C2_SCL: R5.1, U3.30 (PA9), U5.3 (SCL)
/I2C2_SDA: R6.1, U3.31 (PA10), U5.4 (SDA)
/LED: D1.2 (A), U3.38 (PA15)
/NRST: C8.2, J3.7, U3.7 (NRST)
/RFM_DIO0: U1.14 (DIO0), U3.41 (PB5)
/RFM_DIO1: U1.15 (DIO1), U3.42 (PB6)
/RFM_RESET: U1.6 (RESET), U3.25 (PB12)
/SPI2_CS1: U1.5 (NSS), U3.3 (PC14)
/SPI2_CS2: U3.2 (PC13), U4.1 (NCS)
/SPI2_MISO: U1.2 (MISO), U3.27 (PB14), U4.4 (SDO)
/SPI2_MOSI: U1.3 (MOSI), U3.28 (PB15), U4.3 (SDI)
/SPI2_SCK: U1.4 (SCK), U3.26 (PB13), U4.2 (CLK)
/SWCLK: J3.5, U3.37 (PA14)
/SWDIO: J3.4, U3.34 (PA13)
/SWO: J3.6, U3.39 (PB3)
/SW_COM: C13.1, C17.1, L1.1, L2.1, R10.1, SW1.2 (B), U7.2 (EN), U7.3 (VIN), U10.2 (EN), U10.3 (VIN)
/U7_FB: R11.2, R15.1, U7.1 (FB)
/U10_FB: R18.2, R19.1, U10.1 (FB)
/USART3_RX: J3.2, U3.22 (PB11)
/USART3_TX: J3.3, U3.21 (PB10)
GND: C1.1, C2.1, C3.1, C4.1, C5.1, C6.1, C7.1, C8.1, C9.1, C10.1, C11.1, C12.2, C13.2, C14.2, C15.2, C16.2, C17.2, C18.2, C19.2, D2.1, J1.2, J2.S1, J2.S2, J2.S3, J2.S4, J3.1, R3.1, R8.2, R15.2, R16.2, R17.1, R19.2, SW1.1 (A), U1.1 (GND), U1.8 (GND@1), U1.10 (GND@2), U2.B, U2.F, U2.J, U3.8 (VSSA), U3.23 (VSS), U3.35 (VSS), U3.47 (VSS), U4.6 (VPROG), U4.8 (GND), U5.2 (VSS), U6.3 (GND), U7.4 (GND), U8.2 (GND), U9.3 (GND), U10.4 (GND)
unnamed: C10.2, R7.1, Y1.1
unnamed: C16.1, R9.1, U9.5 (DVI)
unnamed: D1.1 (K), R8.1
unnamed: D2.3, R12.2, U8.1, U8.4 (-)
unnamed: L1.2, U7.5 (SW)
unnamed: L2.2, U10.5 (SW)
unnamed: R1.1, U2.E, U2.G
unnamed: R2.1, U2.C
unnamed: R4.1, U2.K
unnamed: R10.2, R16.1, U8.3 (+)
unnamed: R17.2, U9.2 (ADDR)

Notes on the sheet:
Humidity Sensor
HSE Oscillator
Out +5V Filtering
Temperature Sensor
Connectors
R1, R2, R4 Resistors for Pre-Heating
Input +BATT Filtering
LoRaWan
Voltage Divider
PSU
I2C Pull-Up Resistors
Ambient Light Sensor
Metal Oxide Gas Sensor
Voltage Spikes Barrier Diodes
Out +3V3 Filtering
Power Flags
MCU
1 x 100 nF per VDD pin
VDDA Filtering
WEATHER STATION PROJECT
Air Pressure Sensor
Battery Voltage Measurement

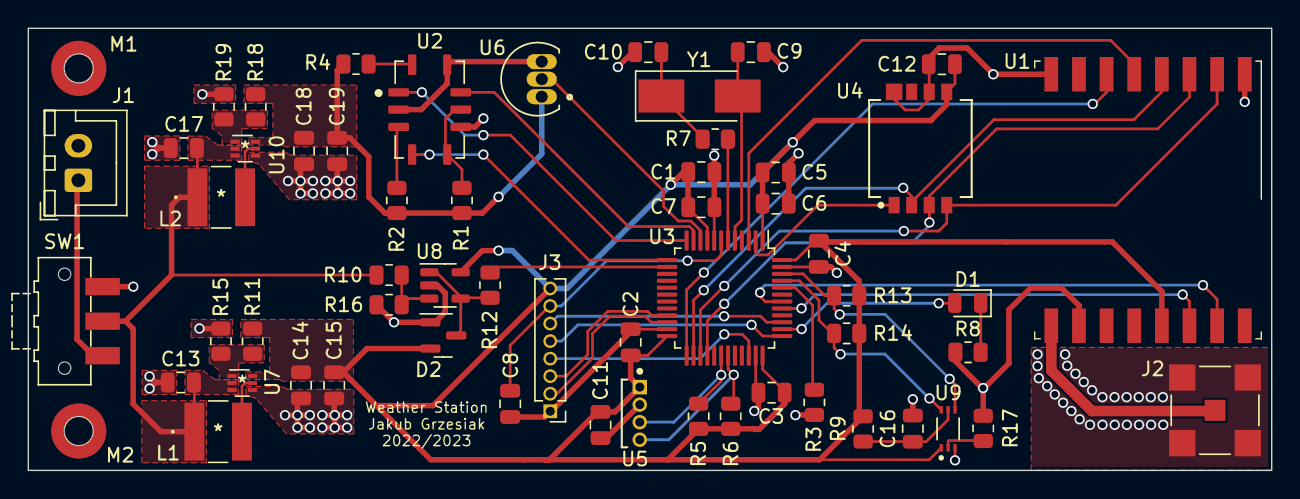
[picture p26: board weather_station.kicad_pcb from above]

Board: 2 copper layers, 90.0 x 32.0 mm, 59 parts (0 on the bottom side), 46 nets.

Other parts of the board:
M1, M2: Mounting_Wuerth_WA-SMSI-M1.6_H2.5mm_9774025633

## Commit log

2023-04-22 BOM, schematics, gerbers and KiCAD files
    [BOM_weather_station.xlsx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]
2023-04-22 Fixed schematics .pdf
2023-05-28 Updated PCB and added 3D view
    [ABM3-8.000MHZ-D2Y-T--3DModel-STEP-400430.STEP, BAT54S,215.STEP, BH1750FVI-TR--3DModel-STEP-56544.STEP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]
2023-05-28 Fixed schematics and src files
    [weather_station-B_Courtyard.gbr, weather_station-B_Cu.gbr, weather_station-B_Mask.gbr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]

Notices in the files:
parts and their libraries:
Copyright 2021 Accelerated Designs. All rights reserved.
